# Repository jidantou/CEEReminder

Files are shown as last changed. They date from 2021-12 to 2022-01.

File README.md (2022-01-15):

# Project introduction
This project is based on STC89C516 chip, aiming at providing services like clock and countdown for students attending CEE.

# Features
### Now available:
Now it contains CEE days remaining, current time and date, two countdowns whose time can be set. All these functions can be set in memu interface.
### Will be avaliable some day:

# Detailed Instructions of Usage
Video is making.

# Project framework
### Hardware
### Software

# LICENSE
This project follows BSD-3-Cause LICENSE

# Contributors
Thanks for 45gfg9's supporting this project greatly.

# About the author
This project was made by myself(jidantou) entirely.If you have some questions, find some bugs or want to provide some suggestions, please contact me by issues or sending [emails](3471699070@qq.com).

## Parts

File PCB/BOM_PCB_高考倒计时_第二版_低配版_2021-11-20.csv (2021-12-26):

ID | Name | Designator | Footprint | Quantity | Manufacturer Part | Manufacturer | Supplier | Supplier Part | Price | Contributor
1 | LED-TH-3mm_G | LED1 | LED-TH_BD3.0_GREEN | 1 | 204-10SYGD/S530-E3 | EVERLIGHT(台湾亿光) |  | C85161 | 0.179 | LCEDA_Lib
2 | 150 | R4 | R0805 | 1 |  |  |  |  |  | LCEDA_Lib
3 | HDR-M-2.54_1x2 | J2,J1 | HDR-M-2.54_1X2 | 2 |  |  | LCSC | C124375 | 0.1043 | LCEDA_Lib
4 | 20p | C1,C2 | C0805 | 2 |  |  |  |  |  | LCEDA_Lib
5 | 10uF | C4 | C0805 | 1 |  |  |  |  |  | LCEDA_Lib
6 | 104 | C5 | C0805 | 1 |  |  |  |  |  | LCEDA_Lib
7 | 33p | C7,C8 | C0805 | 2 |  |  |  |  |  | LCEDA_Lib
8 | 5.1k | R1,R2,R3 | R0805 | 3 |  |  |  |  |  | LCEDA_Lib
9 | 32.768HZ | X1 | OSC-TH_L11.1-W4.7-P4.88 | 1 | 49SAC08000∞2060 | JGHC(晶光华) | LCSC | C443528 | 0.5319 | LCSC
10 | 10uF | C9 | CASE-A_3216 | 1 |  |  |  |  |  | LCEDA_Lib
11 | HDR-F-2.54_1x4 | H1 | HDR-F-2.54_1X4 | 1 |  |  | LCSC | C225501 | 0.4534 | LCEDA_Lib
12 | 10k | R6 | R0805 | 1 |  |  |  |  |  | layout
13 | 按钮 | S1,S2,S3,S4 | 按钮 | 4 |  |  |  |  |  | 1840309377
14 | ICseat-40P | SK1 | DIP-40_L50.8-W17.8-P2.54-LS15.2-BL | 1 | ICseat-40P | BOOMELE | LCSC | C2332 | 0.5628 | 立创EDA官方封装库
15 | 32.786HZ晶振_宽焊盘 | U8 | 32.786HZ晶振_宽焊盘 | 1 |  |  |  |  |  | jidantou
16 | DS1302ZN+T&R | U2 | SOIC-8_L4.9-W3.9-P1.27-LS6.0-BL | 1 | DS1302ZN+T&R | MAXIM | LCSC | C14334 | 11.46 | 87804271zpf
17 | 6脚自锁按钮开关 | U4,U5 | 6脚自锁开关 | 2 |  |  |  |  |  | haorandad

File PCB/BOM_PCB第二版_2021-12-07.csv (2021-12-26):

ID | Name | Designator | Footprint | Quantity | Manufacturer Part | Manufacturer | Supplier | Supplier Part | Price | Contributor
1 | 6脚自锁按钮开关 | U5,U4 | 6脚自锁开关 | 2 |  |  |  |  |  | haorandad
2 | DS1302ZN+T&R | U2 | SOIC-8_L4.9-W3.9-P1.27-LS6.0-BL | 1 | DS1302ZN+T&R | MAXIM | LCSC | C14334 | 11.46 | 87804271zpf
3 | 32.786HZ晶振_宽焊盘 | U8 | 32.786HZ晶振_宽焊盘 | 1 |  |  |  |  |  | jidantou
4 | ICseat-40P | SK1 | DIP-40_L50.8-W17.8-P2.54-LS15.2-BL | 1 | ICseat-40P | BOOMELE | LCSC | C2332 | 0.5628 | 立创EDA官方封装库
5 | 按钮 | S4,S3,S2,S1 | 按钮 | 4 |  |  |  |  |  | 1840309377
6 | 10k | R6 | R0805 | 1 |  |  |  |  |  | layout
7 | HDR-M-2.54_1x2 | J1,J2 | HDR-M-2.54_1X2 | 2 |  |  | LCSC | C124375 | 0.1043 | LCEDA_Lib
8 | HDR-F-2.54_1x4 | H1 | HDR-F-2.54_1X4 | 1 |  |  | LCSC | C225501 | 0.4534 | LCEDA_Lib
9 | 10uF | C9 | CASE-A_3216 | 1 |  |  |  |  |  | LCEDA_Lib
10 | 32.768HZ | X1 | OSC-TH_L11.1-W4.7-P4.88 | 1 | 49SAC08000∞2060 | JGHC(晶光华) | LCSC | C443528 | 0.5319 | LCSC
11 | 5.1k | R3,R2,R1 | R0805 | 3 |  |  |  |  |  | LCEDA_Lib
12 | 33p | C8,C7 | C0805 | 2 |  |  |  |  |  | LCEDA_Lib
13 | 104 | C5 | C0805 | 1 |  |  |  |  |  | LCEDA_Lib
14 | 10uF | C4 | C0805 | 1 |  |  |  |  |  | LCEDA_Lib
15 | 20p | C1,C2 | C0805 | 2 |  |  |  |  |  | LCEDA_Lib
16 | 150 | R4 | R0805 | 1 |  |  |  |  |  | LCEDA_Lib
17 | LED-TH-3mm_G | LED1 | LED-TH_BD3.0_GREEN | 1 | 204-10SYGD/S530-E3 | EVERLIGHT(台湾亿光) |  | C85161 | 0.179 | LCEDA_Lib

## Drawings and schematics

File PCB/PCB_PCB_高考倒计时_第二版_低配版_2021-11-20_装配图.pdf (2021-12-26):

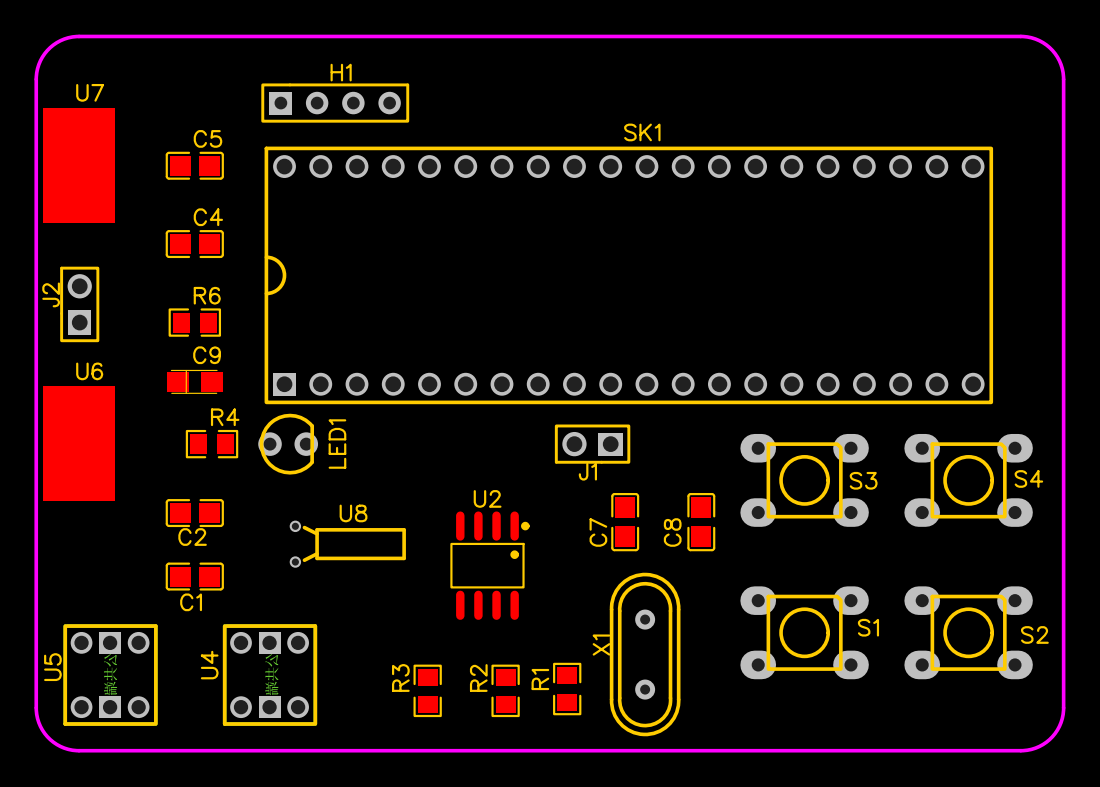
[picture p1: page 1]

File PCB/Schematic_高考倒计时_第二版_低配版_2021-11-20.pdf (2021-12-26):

# MCU模块 DS1302模块

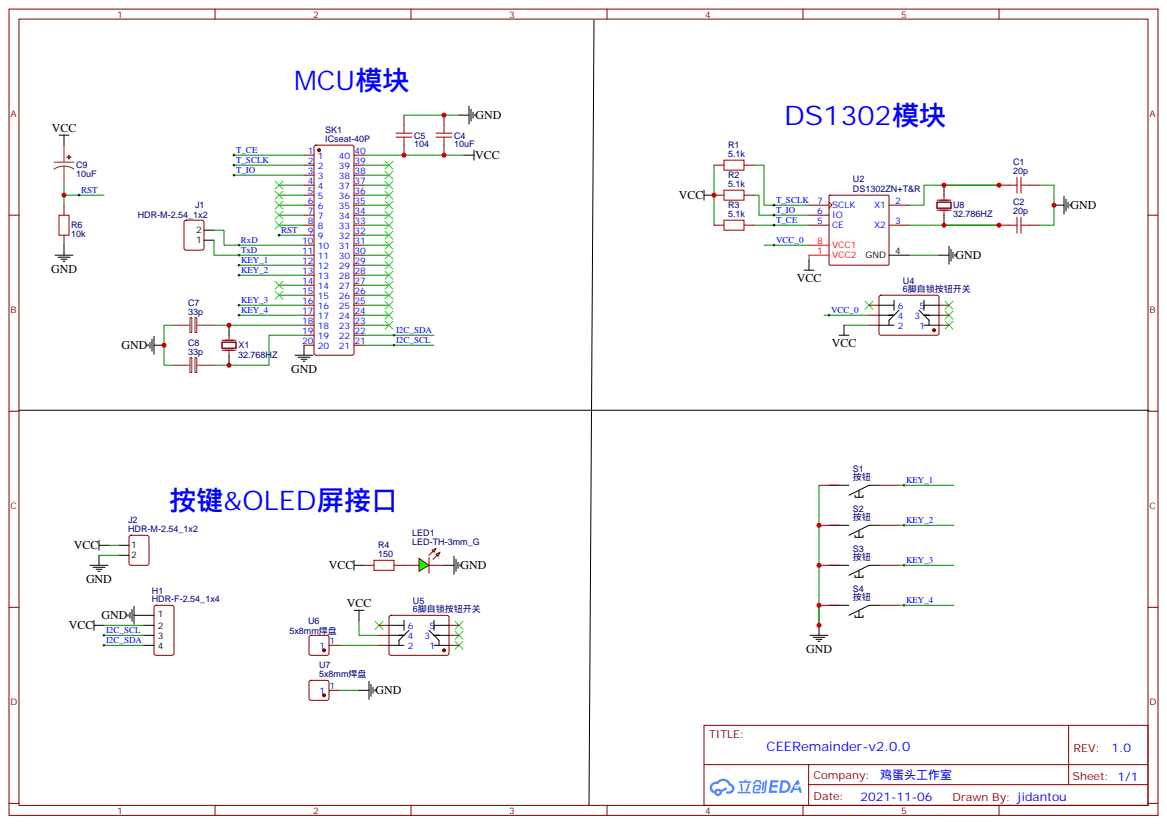
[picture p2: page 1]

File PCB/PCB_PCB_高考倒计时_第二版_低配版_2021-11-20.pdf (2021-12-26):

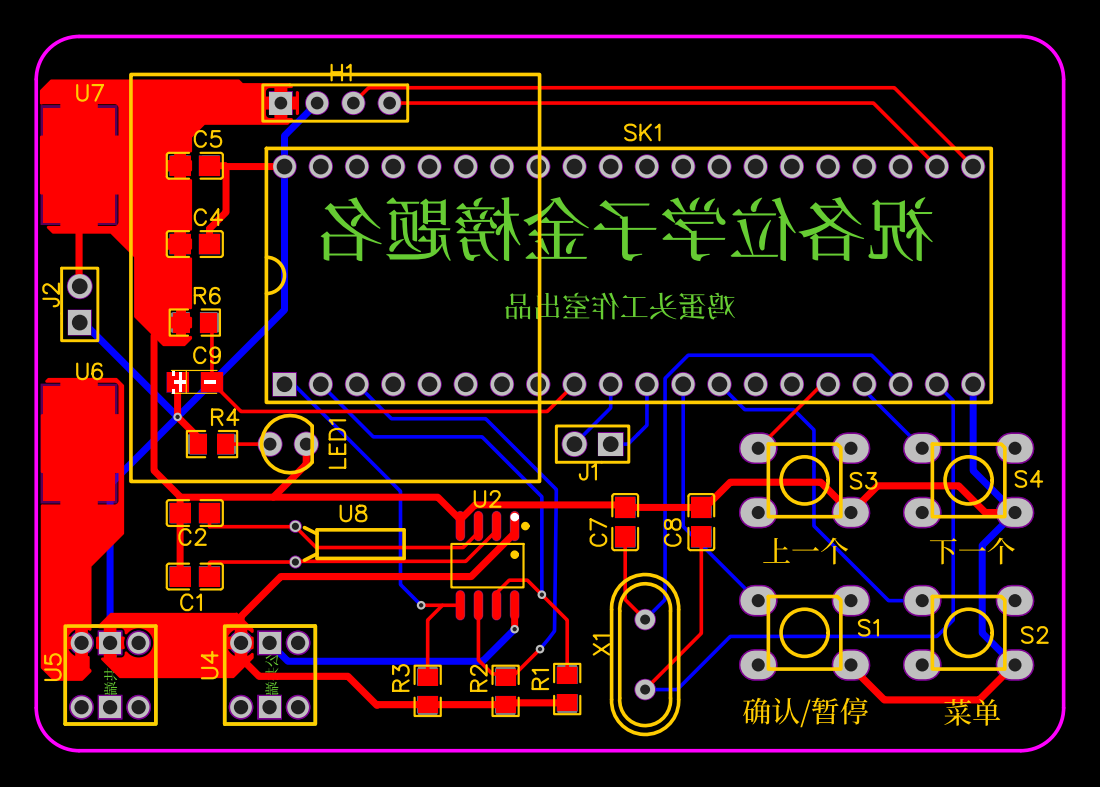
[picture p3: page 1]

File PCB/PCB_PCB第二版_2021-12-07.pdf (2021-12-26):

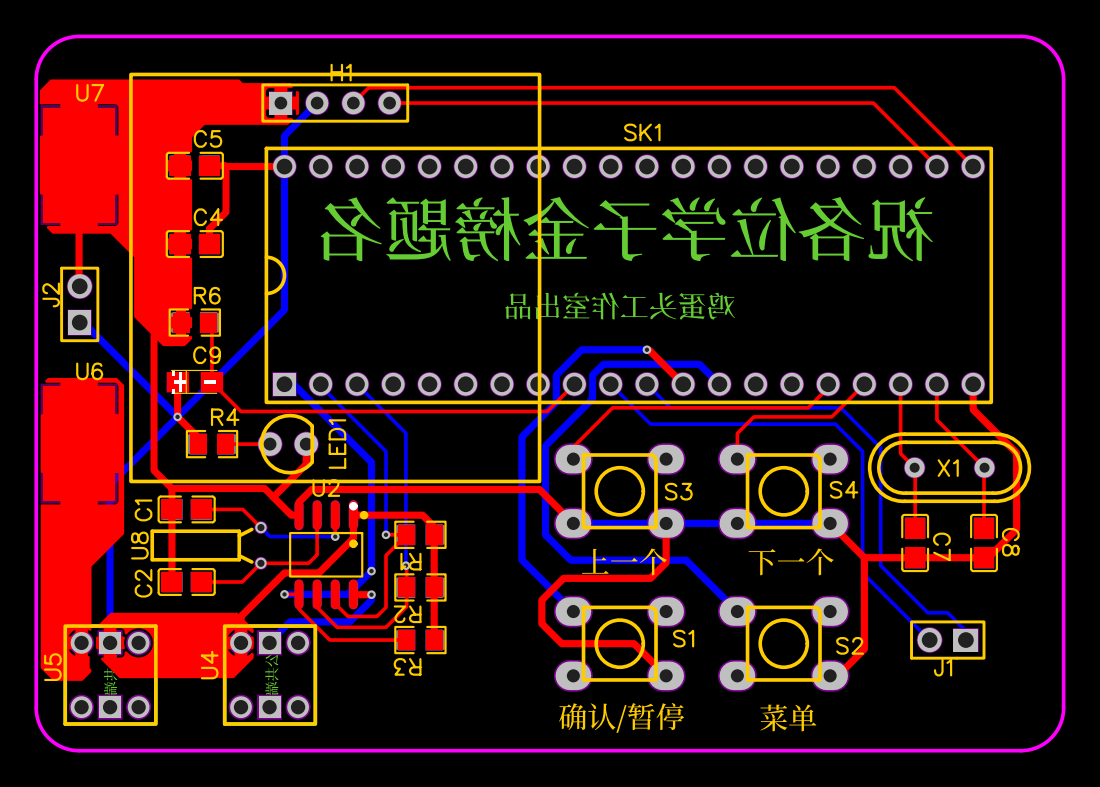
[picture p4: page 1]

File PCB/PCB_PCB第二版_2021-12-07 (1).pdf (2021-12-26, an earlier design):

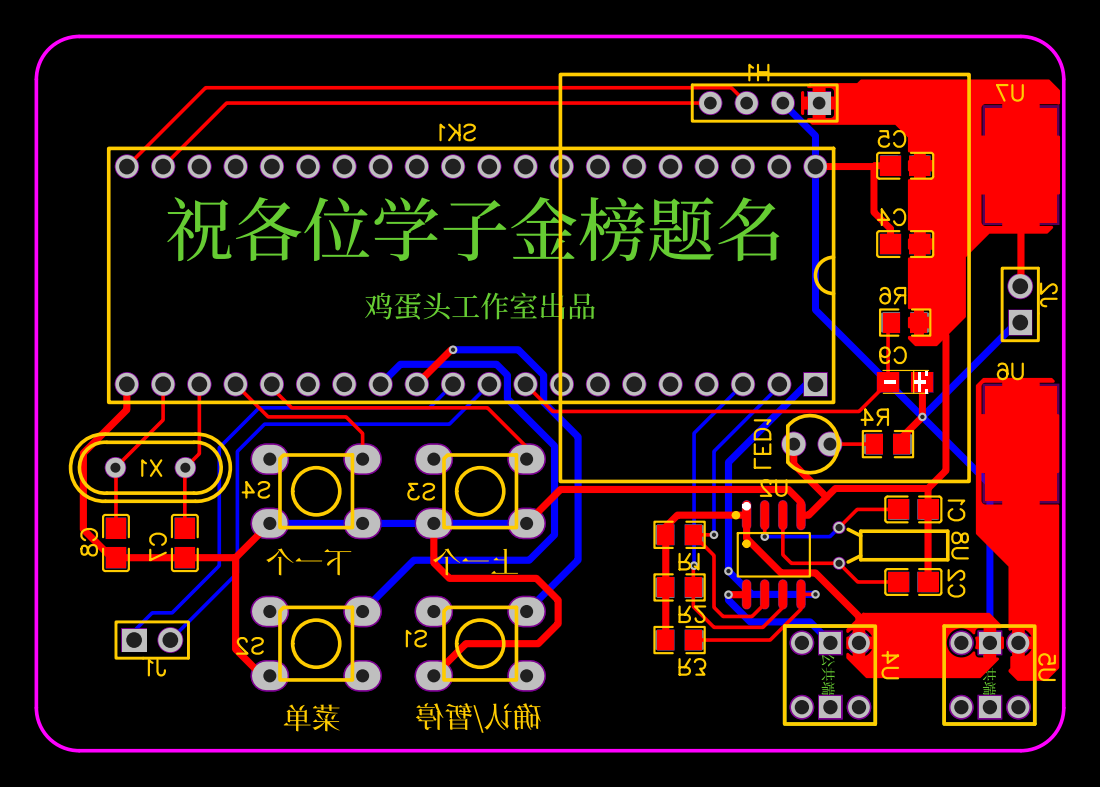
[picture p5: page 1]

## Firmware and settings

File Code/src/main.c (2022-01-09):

// main.c
#include "global.h"
#include "DS1302.h"
#include "Display.h"
#include "GUI.h"
#include "Process.h"

static u16 Timer = 0, second = 0;
uchar sleep = 0;	// 0 for no sleeping

void main()
{
	OLED_Init();
	//DS1302SetTime();
	InterruptInit();
	//UsartInit();
	key0 = 1;
	key1 = 1;
	key2 = 1;
	key3 = 1;

	GUI_Start();
	delay_long(10);
	OLED_Cls();
	DS1302ReadTime();
	TR0=1;

	//UsartSend(0x88);

	while(1)
	{
		if(key2 == 0)
		{
			delay(800);
			if(key2 == 0)
			{
				while(!key2);
				KeySign |= 0x02;
				second = 0;
			}
		}
		if(key3 == 0)
		{
			delay(800);
			if(key3 == 0)
			{
				while(!key3);
				KeySign |= 0x01;
				second = 0;
			}
		}
		
		//UsartSend(0xFF);
		KeyPro();
		//UsartSend(0x00);
	}
}

void Int0() interrupt 0
{
	delay(800);
	if(key0 == 0)
	{
		while(!key0);
		if(sleep == 1)
		{
			sleep = 0;
			DS1302ReadTime();
			CountPro(0);
			CountPro(1);
		}
		else KeySign |= 0x08;
		second = 0;
	}
}

void Int1() interrupt 2
{
	delay(800);
	if(key1 == 0)
	{
		while(!key1);
		if(sleep == 1)
		{
			sleep = 0;
			DS1302ReadTime();
			CountPro(0);
			CountPro(1);
		}
		else KeySign |= 0x04;
		second = 0;
	}
}

void Timer0() interrupt 1
{
	TH0 = 0xFC;  //1ms
	TL0 = 0x18;
	Timer++;
	if(Timer % 200 == 0)
	{
		// debug
		//GUI_Test(debug);
		//delay(5000);	
		//OLED_Cls();
		//UsartSend(Timer);
		//debug = ShowMode >> 7;			

		Process();

		if(ShowMode & 0x80)
		{
			OLED_Cls();
			ShowMode &= 0x7F;
		}
		switch(ShowMode & 0x7F)
		{
			case 0: GUI_CEE(); break;
			case 1:	GUI_Time(0); break;
			case 2:	GUI_Date(0); break;
			case 3:	GUI_CountDown(0, 0); break;
			case 4:	GUI_CountDown(1, 0); break;
			case 5:	GUI_Memu0(); break;
			case 6:	GUI_Memu1(); break;
			case 7: GUI_SetCEE(); break;
			case 8: GUI_Time(1); break;
			case 9: GUI_Date(1); break;
			case 10: GUI_CountDown(0, 1); break;
			case 11: GUI_CountDown(1, 1); break;
			default: ShowMode = 0x00; break;
		}
	}

	if(Timer == 1000)
	{
		Timer = 0;
		second++;
		DS1302ReadTime();
		CountPro(0);
		CountPro(1);
	}

	if(second == 20)
	{
		second = 0;
		OLED_Cls();
		sleep = 1;
		PCON |= 0x02;
	}
}

/*
// DEBUG	
//debug
void Usart() interrupt 4
{
	TI = 0;
}
*/

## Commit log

2021-12-26 新建 code
2021-12-26 PCB publish.Designed by lceda.cn.
2021-12-26 删除文件 code/.keep
2021-12-26 code publish
    [BOM_立创EDA_PCB_2021-11-04.csv, 立创EDA_PCB_2021-11-04.pcbdoc]
2021-12-26 删除文件 README.md
2021-12-26 删除文件 README.en.md
2021-12-26 删除文件 code/README.md
2021-12-26 删除文件 code/README_cn.md
2021-12-26 删除文件 code/code
2021-12-26 删除文件 code/PCB
    [BOM_立创EDA_PCB_2021-11-04.csv, 立创EDA_PCB_2021-11-04.pcbdoc]
2021-12-26 删除文件 code
2021-12-26 删除文件 PCB
    [BOM_立创EDA_PCB_2021-11-04.csv, 立创EDA_PCB_2021-11-04.pcbdoc]
2022-01-01 删除文件 Code/inc
2022-01-01 删除文件 Code/src
2022-01-09 Update code v2.2, have repaired a few bugs. v2.2, have repaired a few bugs.
    [main.c]
